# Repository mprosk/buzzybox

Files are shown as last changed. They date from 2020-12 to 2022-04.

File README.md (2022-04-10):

# buzzybox
Simple multi oscillator drone box

## Design and Assembly Notes
- More or less any NPN transistor will work, but not all transistors will go into reverse avalanche mode. I recommend you test one of the transistors you intend to use on a breadboard to make sure they will oscillate. Refer to the circuit in the reverse avalanche article in the `datasheets` folder
- The base lead of the transistors needs to be snipped, otherwise the oscillator may not work. Refer to the reverse avalanche article in the `datasheets` folder
- The footprint for the potentiometers is a little off and you may need to widen the mounting holes with a drill (the electrical holes are fine)
- The footprint for the headphone jack is upside down so it needs to go on the underside of the bottom board, not on top
- The output level is stupid low so just be aware it's going to require a lot of amplification to be useful
- Voltage range can be anything from 12-24 ish volts. Increasing the supply voltage will increase the relative pitch of all oscillators

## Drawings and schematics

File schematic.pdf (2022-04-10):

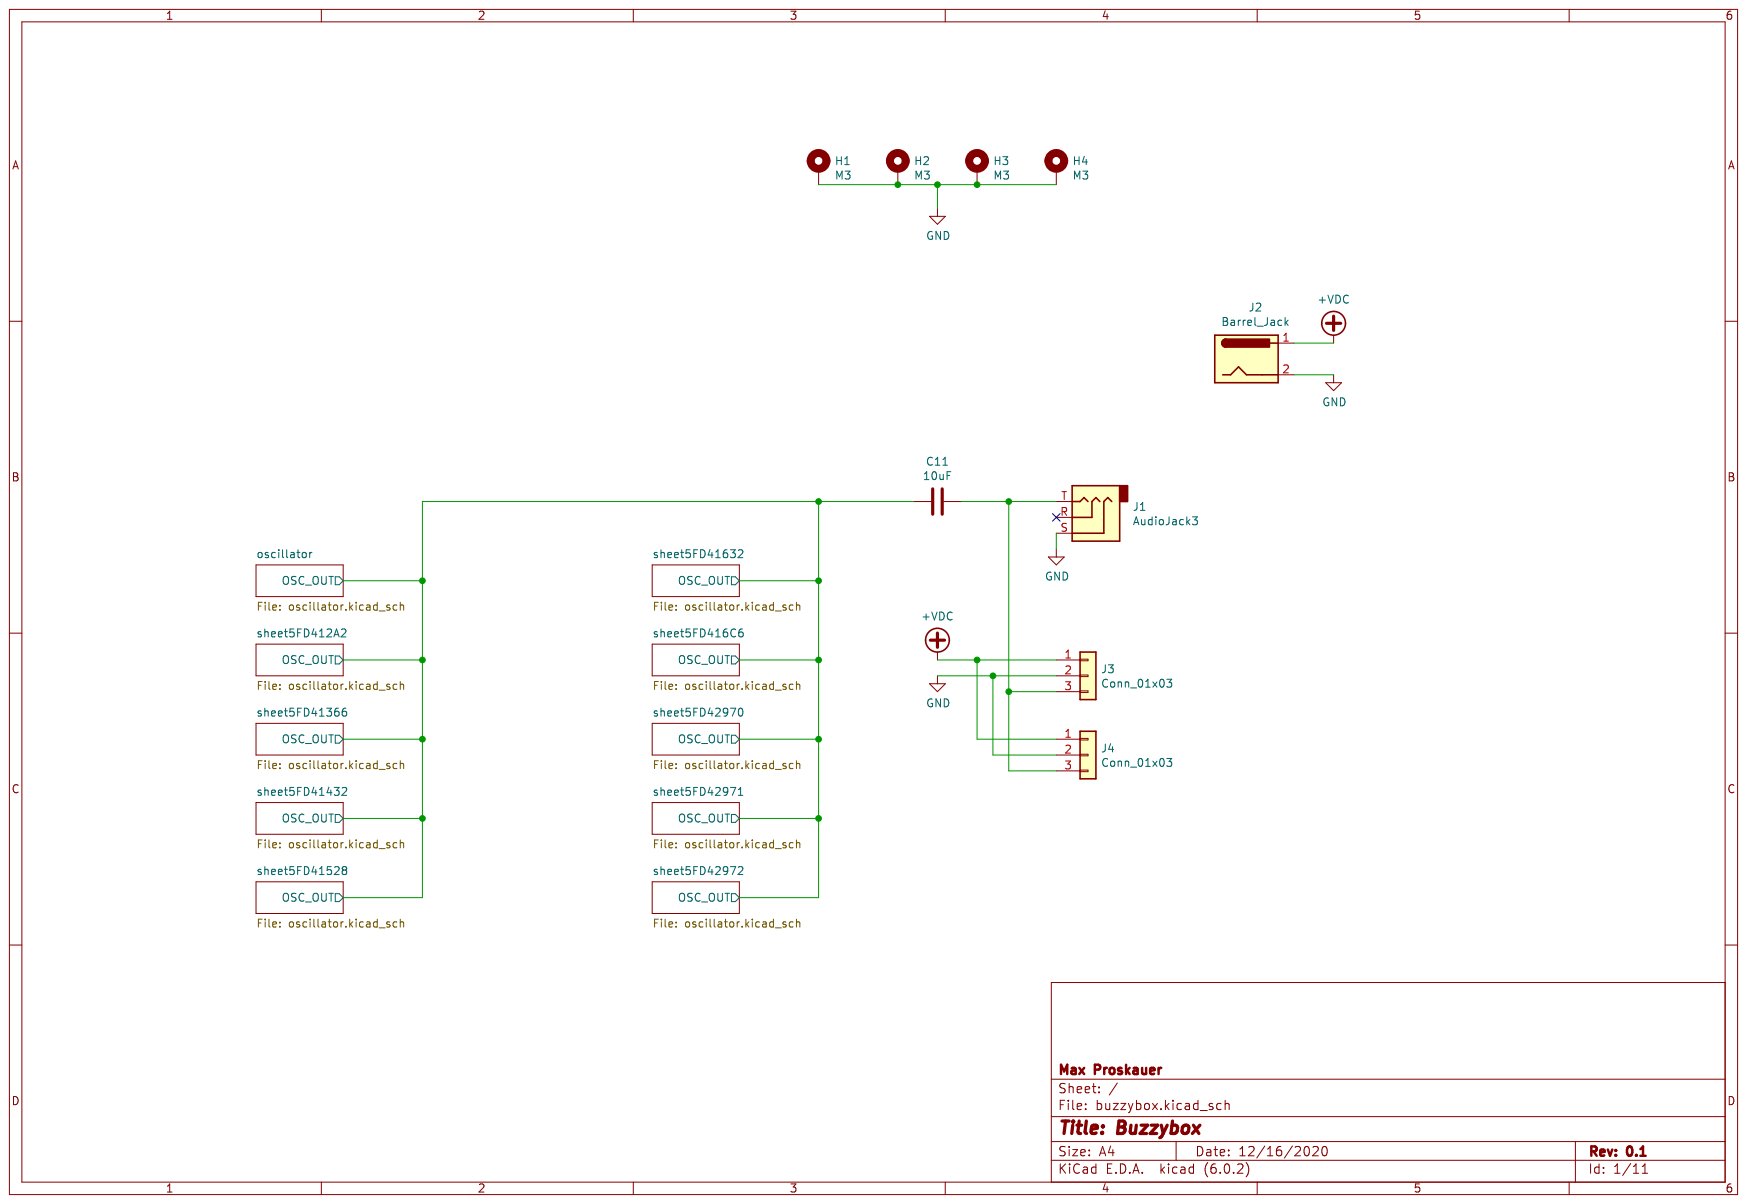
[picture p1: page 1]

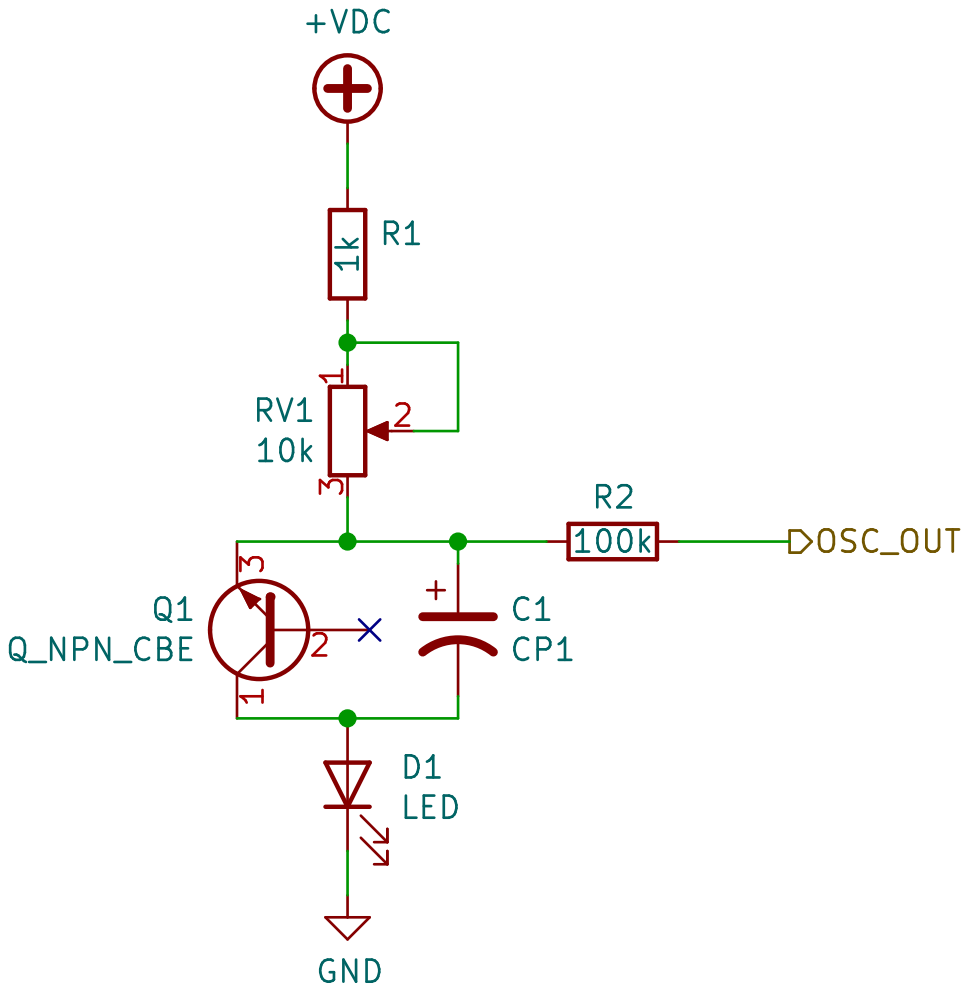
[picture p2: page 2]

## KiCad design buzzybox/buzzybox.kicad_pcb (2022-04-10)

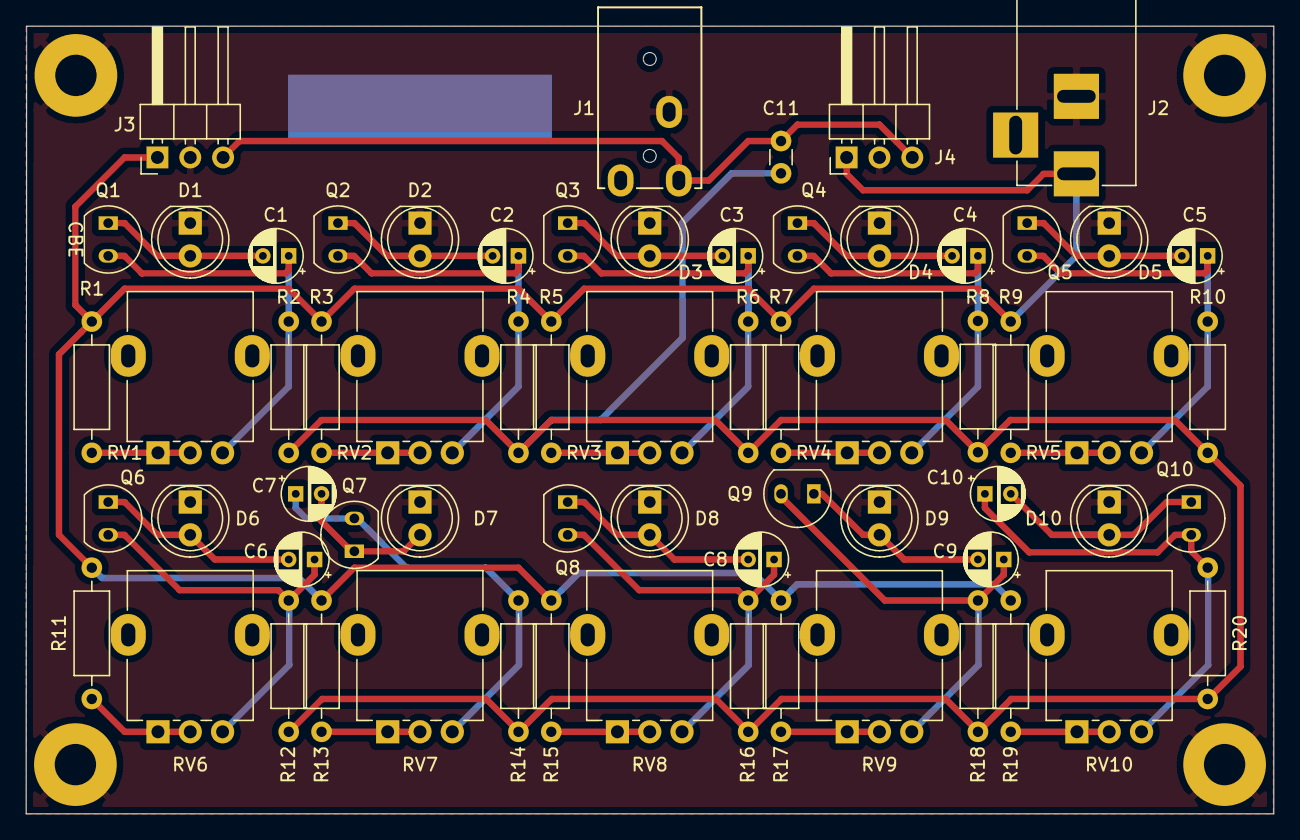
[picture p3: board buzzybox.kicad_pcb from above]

Board: 2 copper layers, 96.6 x 61.0 mm, 69 parts (0 on the bottom side), 34 nets.

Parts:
C1, C2, C3, C4, C5, C6, C7, C8, C9, C10: CP1; CP_Radial_D4.0mm_P2.00mm
C11: 0.1uF; C_Disc_D3.0mm_W1.6mm_P2.50mm
D1, D2, D3, D4, D5, D6, D7, D8, D9, D10: LED; LED_D5.0mm
H1, H2, H3, H4: M3; MountingHole_3.2mm_M3_Pad
J1: AudioJack3; STX-3000
J2: Barrel_Jack; BARREL_JACK
J3, J4: Conn_01x03; PinHeader_1x03_P2.54mm_Horizontal
Q1, Q2, Q3, Q4, Q5, Q6, Q7, Q8, Q9, Q10: Q_NPN_CBE; TO-92-2
R1, R3, R5, R7, R9, R11, R13, R15, R17, R19: 1k; R_Axial_DIN0207_L6.3mm_D2.5mm_P10.16mm_Horizontal
R2, R4, R6, R8, R10, R12, R14, R16, R18, R20: 100k; R_Axial_DIN0207_L6.3mm_D2.5mm_P10.16mm_Horizontal
RV1, RV2, RV3, RV4, RV5, RV6, RV7, RV8, RV9, RV10: 10k; Potentiometer_Alpha_RD901F-40-00D_Single_Vertical

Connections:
+VDC: J2.1, J3.1, J4.1, R1.1, R3.1, R5.1, R7.1, R9.1, R11.1, R13.1, R15.1, R17.1, R19.1
/oscillator/OSC_OUT: C11.1, R2.1, R4.1, R6.1, R8.1, R10.1, R12.1, R14.1, R16.1, R18.1, R20.1
GND: D1.1, D2.1, D3.1, D4.1, D5.1, D6.1, D7.1, D8.1, D9.1, D10.1, H1.1, H2.1, H3.1, H4.1, J1.S, J2.2, J3.2, J4.2
unnamed: C1.1, Q1.3, R2.2, RV1.3
unnamed: C1.2, D1.2, Q1.1
unnamed: C2.1, Q2.3, R4.2, RV2.3
unnamed: C2.2, D2.2, Q2.1
unnamed: C3.1, Q3.3, R6.2, RV3.3
unnamed: C3.2, D3.2, Q3.1
unnamed: C4.1, Q4.3, R8.2, RV4.3
unnamed: C4.2, D4.2, Q4.1
unnamed: C5.1, Q5.3, R10.2, RV5.3
unnamed: C5.2, D5.2, Q5.1
unnamed: C6.1, Q6.3, R12.2, RV6.3
unnamed: C6.2, D6.2, Q6.1
unnamed: C7.1, Q7.3, R14.2, RV7.3
unnamed: C7.2, D7.2, Q7.1
unnamed: C8.1, Q8.3, R16.2, RV8.3
unnamed: C8.2, D8.2, Q8.1
unnamed: C9.1, Q9.3, R18.2, RV9.3
unnamed: C9.2, D9.2, Q9.1
unnamed: C10.1, Q10.3, R20.2, RV10.3
unnamed: C10.2, D10.2, Q10.1
unnamed: C11.2, J1.T, J3.3, J4.3
unnamed: R1.2, RV1.1, RV1.2
unnamed: R3.2, RV2.1, RV2.2
unnamed: R5.2, RV3.1, RV3.2
unnamed: R7.2, RV4.1, RV4.2
unnamed: R9.2, RV5.1, RV5.2
unnamed: R11.2, RV6.1, RV6.2
unnamed: R13.2, RV7.1, RV7.2
unnamed: R15.2, RV8.1, RV8.2
unnamed: R17.2, RV9.1, RV9.2
unnamed: R19.2, RV10.1, RV10.2

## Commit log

2020-12-15 Initial layout complete
    [buzzybox.kicad_pcb, buzzybox.sch, oscillator.sch]
2020-12-15 complete mini layout
    [buzzybox.kicad_pcb, buzzybox.sch, oscillator.sch]
2020-12-17 Add faceplate
    [faceplate.kicad_pcb, faceplate.sch]
2020-12-17 finalize main PCB after parts recieved
    [buzzybox.kicad_pcb, buzzybox.sch, oscillator.sch]
2020-12-18 complete refit
    [buzzybox.kicad_pcb]
2022-04-10 Add gerber files
    [buzzybox-B_Cu.gbr, buzzybox-B_Mask.gbr, buzzybox-B_Paste.gbr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]
2022-04-10 Update to KiCAD6 and created schematic PDF
    [buzzybox.kicad_pcb, buzzybox.kicad_sch, buzzybox.sch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]
2022-04-10 Include PDF of schematic
